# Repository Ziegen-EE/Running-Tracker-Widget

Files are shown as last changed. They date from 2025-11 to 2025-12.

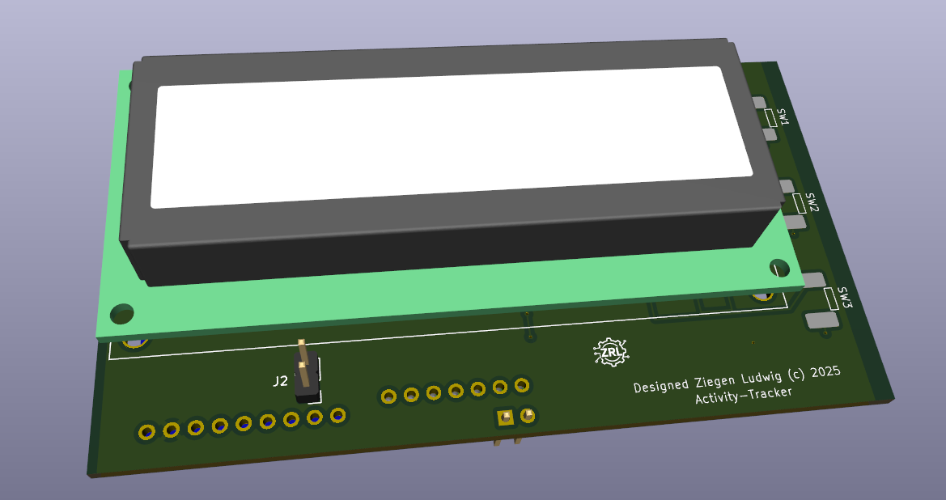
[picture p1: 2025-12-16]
Running-Tracker/KiCad/PCB/3D_PCB.png

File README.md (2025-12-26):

# Running Tracker Widget  
*A compact Arduino-based wearable for tracking pace, distance, and run duration.*

---

## Overview
The **Running Tracker Widget** is a portable, battery-powered device designed to measure and display **running metrics** such as **pace**, **distance**, and **elapsed time**.  
Built around the **Arduino Pro Mini**, this system integrates GPS positioning, user controls, and a display interface to deliver accurate real-time tracking data in a lightweight form factor.  

This project highlights hands-on skills in **embedded systems**, **circuit design**, and **hardware integration**, forming a complete end-to-end electrical engineering prototype.

---

## System Features
- **Arduino Pro Mini Core** – Compact 5V microcontroller board for low-power applications  
- **Adafruit Ultimate GPS Module** – Provides accurate positional data (lat/lon, altitude, speed, and time)  
- **LCD Display with Adjustable Resistor** – Displays pace, distance, and time in real-time  
- **Pololu LV Power Switch** – Enables safe and efficient power management for battery use  
- **User Input Buttons** – Right-angle momentary push buttons for start/stop and mode navigation  
- **Passive Components** – Decoupling capacitors and precision resistors for signal stability and protection  
- **9V Battery Snap Connector** – Supports portable power input with quick connection  

---

## Bill of Materials (BOM)

You can view the full interactive BOM spreadsheet here:  
👉 [**Running Tracker BOM – Google Sheets**](https://docs.google.com/spreadsheets/d/1CWu7IO52Xdz1FhUTgCzN4FMrNsjh3O-xI5pumeO5So4/edit?usp=sharing)

| # | Component | Manufacturer | MPN | Qty | Description / Notes |
|---|---|---|---|-----|---|
| 1 | Arduino Pro Mini Socket | SparkFun | DEV-11113 | 1 | 5V, 16MHz, core microcontroller board |
| 2 | Adafruit Ultimate GPS | Adafruit | 746 | 1 | High-accuracy GPS module with integrated antenna |
| 3 | Pololu LV Power Switch | Pololu | 2808 | 1 | Low-voltage switch for efficient battery control |
| 4 | LCD + Variable Resistor | Adafruit | 181 | 1 | Display and control interface |
| 5 | Right Angle Push Button | C&K | 611-KSS223GLFG | 3 | User input buttons |
| 6 | Capacitor 10µF | TAIYO YUDEN | MCASL21GBB7106KTNA01 | 1 | Power line stabilization |
| 7 | Capacitor 0.1µF | KYOCERA AVX | KAM21BR71H104JM | 1 | Signal filtering |
| 8 | Resistor 220Ω | Panasonic | ERJ-S06F2200V | 1 | Current limiting |
| 9 | Resistor 10kΩ | KOA Speer | SG73P2ARTTD103G | 3 | Voltage division and logic pull-ups |
| 10 | 9V Battery Snap | Bourns | LS-00033 | 1 | Power supply connector |

---

## Functional Overview
1. **GPS Data Acquisition:** The Adafruit GPS module provides NMEA data for time, position, and velocity.  
2. **Microcontroller Processing:** The Arduino Pro Mini calculates pace and distance based on GPS data.  
3. **User Interaction:** Push buttons allow start/stop control and data viewing.  
4. **Display Output:** The LCD module shows real-time run statistics.  
5. **Power Regulation:** The Pololu switch ensures stable and safe power control from a 9V source.

---

## Technical Specifications
- **Operating Voltage:** 5V  
- **Input Power:** 9V battery (via snap connector)  
- **Microcontroller:** ATmega328P (Arduino Pro Mini)  
- **Display Interface:** Parallel/Serial LCD  
- **Sensors:** GPS (Adafruit Ultimate GPS)  
- **User Inputs:** 3x push buttons  
- **Enclosure:** Compatible with 3D-printed housing or handheld casing  

---

## Development Tools
- **IDE:** Arduino IDE  
- **Language:** C/C++  
- **Libraries:** `Adafruit_GPS`, `LiquidCrystal`, `SoftwareSerial`  
- **Simulation / Schematic:** KiCad or EasyEDA  

---

## Future Enhancements
- Add accelerometer or IMU sensor for step-based distance correction  
- Integrate Bluetooth for mobile sync  
- Log data to microSD for long-term performance tracking  
- Optimize firmware for lower power consumption

---

### PCB Manufacturing
The PCB layout and Gerber files were created following **[3DayPCBs](https://3daypcbs.com)** standard manufacturing specifications.  
Key parameters include:
- 1.6 mm board thickness  
- 1 oz copper weight  
- 6 mil minimum trace/space  
- Standard FR-4 substrate  
- Through-hole and SMD mixed design  

Compatibility with other PCB manufacturers may require DRC rule adjustments.

---

## License
This project is licensed under the [MIT License](LICENSE).  
Feel free to use and modify with attribution.

**PCB Design Notice:**  
All PCB and Gerber files included in this repository are designed according to **[3DayPCBs](https://3daypcbs.com)** manufacturing specifications, including board thickness, copper weight, trace width, and drill tolerances.  
Users adapting the design for other manufacturers should verify compatibility and adjust design rules accordingly.

---

## Acknowledgments

This project makes use of the [Arduino KiCad Library](https://github.com/Alarm-Siren/arduino-kicad-library)  
by **Alarm-Siren**, distributed under the [MIT License](https://github.com/Alarm-Siren/arduino-kicad-library/blob/main/LICENSE).

The library was used for schematic and footprint references during PCB design.

---

## Sponsorship & Support

This project is proudly supported by the  
**[School District 38 CTE (Career & Technical Education) Program](https://www.lewispalmer.org/cte)**.  

Their sponsorship provided access to electronic components, fabrication tools, and resources essential for the development and testing of the Activity Tracker Widget.  
Special thanks to the instructors and staff who promote hands-on STEM and engineering education.

## PCB Manufacturing Support

PCB fabrication for this project can be reliably handled by **PCBWay**, a professional PCB manufacturing and assembly service widely used for prototyping and medium to large-scale production.

PCBWay is well-suited for projects like my **Running Tracker Widget**, which combine through-hole and SMD components in a compact embedded design. Their capabilities support iterative hardware development and manufacturing constraints common in wearable and portable electronics.

### Relevant Capabilities
- Standard **FR-4 PCB fabrication** with configurable thickness and copper weight  
- Support for **mixed through-hole and SMD designs**  
- Optional **PCB assembly (PCBA)** for populated boards  
- Fast turnaround times suitable for prototyping and validation  

Design files created for this project are adapted for 3DayPCBs, although manufacturing specifications are well within their capabilities!!!

Additional information is available at:  
👉 **https://www.pcbway.com**

PCBWay actively supports open-source hardware projects and educational engineering development.

---

## Author
**[Ziegen Ludwig]**  
Electrical Engineering Student | Embedded Systems Developer  
🔧 *Focused on IoT, microcontroller design, and wearable electronics.*

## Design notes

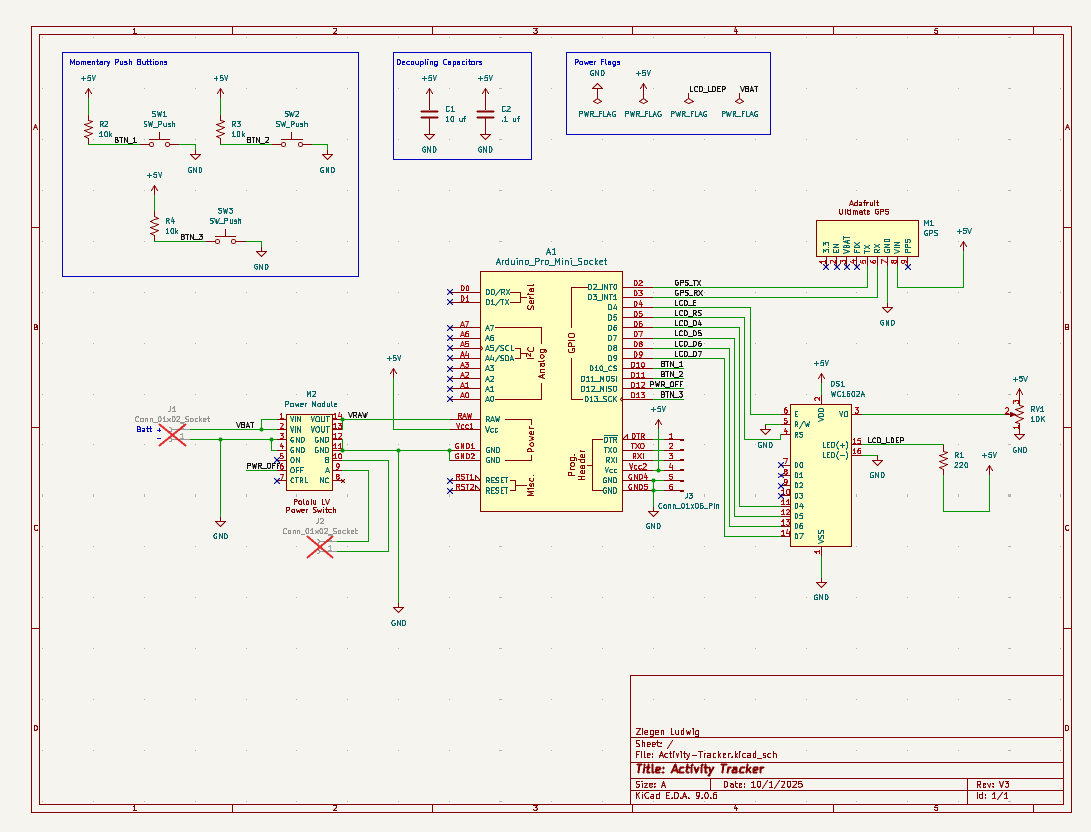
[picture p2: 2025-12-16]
Running-Tracker/KiCad/Schematic/schematic.png.png

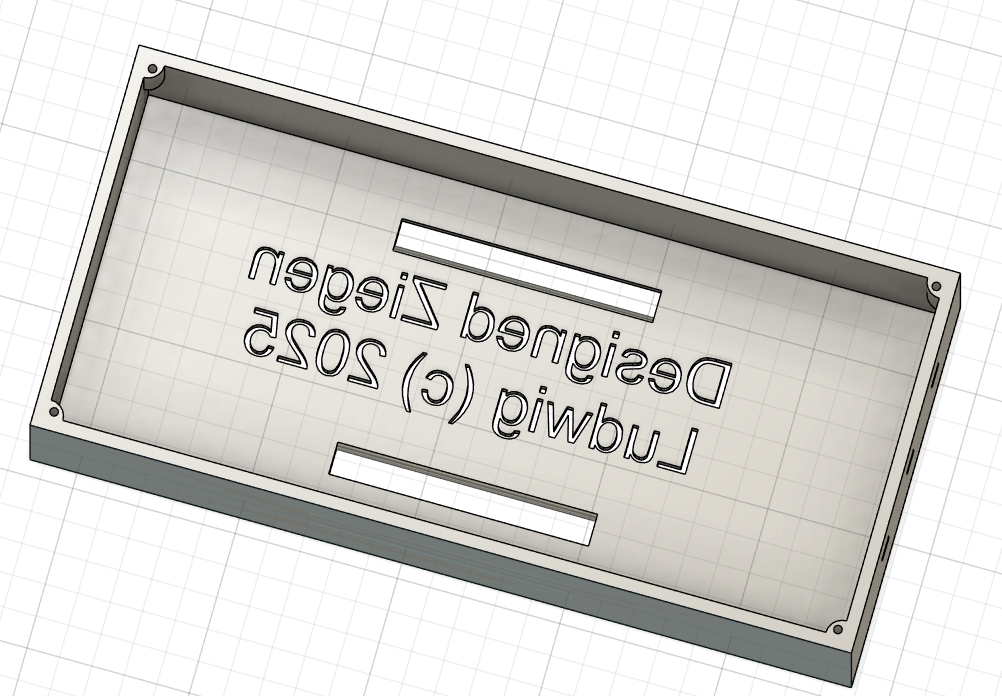
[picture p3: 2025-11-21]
Running-Tracker/3D-Modeled-Case/Running-Tracker-Base.png

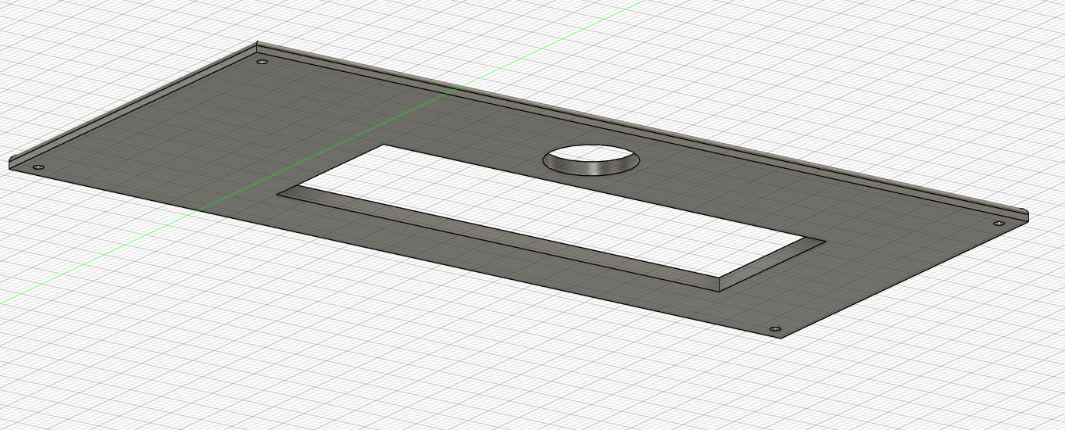
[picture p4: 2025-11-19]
Running-Tracker/3D-Modeled-Case/Running-Tracker-Lid.png

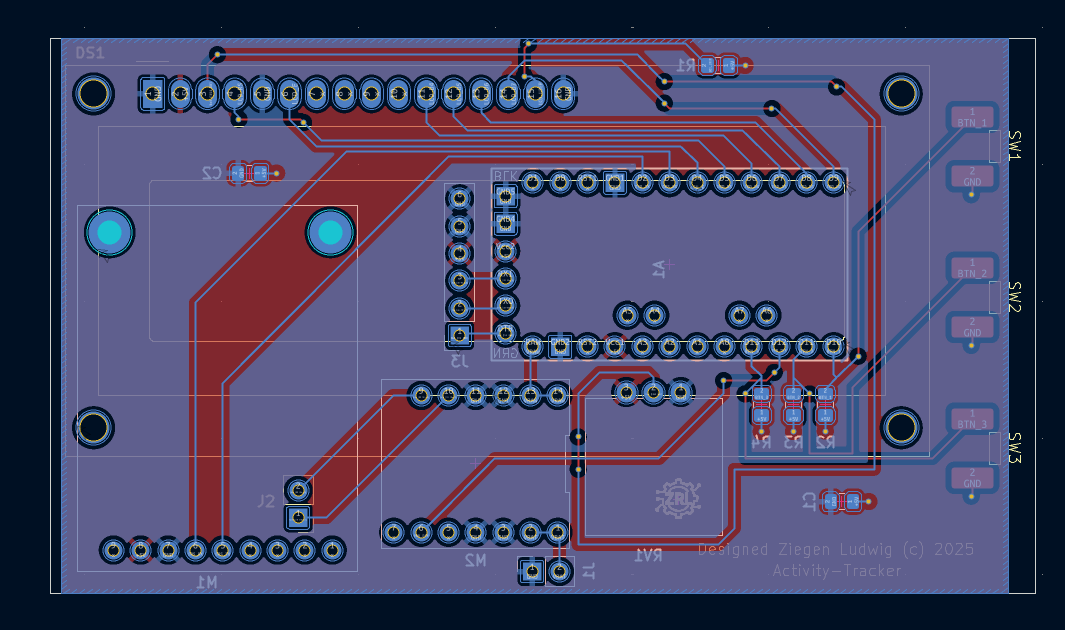
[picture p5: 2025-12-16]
Running-Tracker/KiCad/PCB/2D_PCB.png

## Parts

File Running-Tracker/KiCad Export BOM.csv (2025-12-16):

Reference | Qty | Value | DNP | Exclude from BOM | Exclude from Board | Footprint | Datasheet
A1 | 1 | Arduino_Pro_Mini_Socket |  |  |  | arduino-library:Arduino_Pro_Mini_Socket | https://docs.arduino.cc/retired/boards/arduino-pro-mini
C1 | 1 | 10 uf |  |  |  | Capacitor_SMD:C_0805_2012Metric_Pad1.18x1.45mm_HandSolder | ~
C2 | 1 | .1 uf |  |  |  | Capacitor_SMD:C_0805_2012Metric_Pad1.18x1.45mm_HandSolder | ~
DS1 | 1 | WC1602A |  |  |  | Display:WC1602A | http://www.wincomlcd.com/pdf/WC1602A-SFYLYHTC06.pdf
J1,J2 | 2 | Conn_01x02_Socket | DNP |  |  | Connector_PinHeader_2.54mm:PinHeader_1x02_P2.54mm_Vertical | ~
J3 | 1 | Conn_01x06_Pin |  |  |  | Connector_PinHeader_2.54mm:PinHeader_1x06_P2.54mm_Vertical | ~
M1 | 1 | GPS |  |  |  | Adafruit:Adafruit Ultimate GPS
M2 | 1 | Power Module |  |  |  | Pololu_PWR_SW_LV:Pololu LV Power Switch
R1 | 1 | 220 |  |  |  | Resistor_SMD:R_0805_2012Metric_Pad1.20x1.40mm_HandSolder | ~
R2,R3,R4 | 3 | 10k |  |  |  | Resistor_SMD:R_0805_2012Metric_Pad1.20x1.40mm_HandSolder | ~
RV1 | 1 | 10K |  |  |  | Potentiometer_THT:Potentiometer_Vishay_148-149_Single_Vertical | ~
SW1,SW2,SW3 | 3 | SW_Push |  |  |  | KSS223G_LFG:KSS223G LFG | ~

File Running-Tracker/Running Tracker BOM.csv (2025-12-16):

Column 1 | Reference Designator | DNP | Part Name | Manufacturer | MPN | Qty | Footprint | Link | Notes | Price | Total Price
1 | A1 | No | Arduino Pro Mini Socket | SparkFun | DEV-11113 | 1 | Module | Link | 5v | 11.25 | 100.07
2 | M1 | No | Adafruit Ultimate GPS | Adafruit | 746 | 1 | Module | Link |  | 29.95
3 | M2 | No | Pololu LV Power Switch | Pololu | 2808 | 1 | Module | Link |  | 4.95
4 | DS1 | No | LCD + Varible Resistor | Adafruit | 181 | 1 | Module | Link |  | 9.95
5 | SW1, SW2, SW3 | No | Right Angle Momentary Push Button | C&K | 611-KSS223GLFG | 3 | SMD | Link |  | 0.97
6 | C1 | No | Capacitor | TAIYO YUDEN | MCASL21GBB7106KTNA01 | 1 | SMD | Link | 10uF | 0.45
7 | C2 | No | Capacitor | KYOCERA AVX | KAM21BR71H104JM | 1 | SMD | Link | .1uF | 0.2
8 | R1 | No | Resistor | Panasonic | ERJ-S06F2200V | 1 | SMD | Link | 220 | 0.31
9 | R2, R3, R4 | No | Resistor | KOA Speer | SG73P2ARTTD103G | 3 | SMD | Link | 10K | 0.22
10 | J1 | Yes | 9V Battery Snap-On | Bourns | 375-LS-00033 | 1 | N/a | Link |  | 3.14
11 | J2 | Yes | Momentary Push Button | Adafruit | 1505 | 1 | N/a | Link |  | 0.95
12 | J3 | No | 1x6 Vertical Pin Header | Amphenol FCI | 649-68001-406HLF | 1 | Pin Strip | Link |  | 0.34
13 | N/a | Yes | 3D Modeled Case | N/a | N/a | 1 | N/a | N/a |  | 0
14 | N/a | Yes | Battery | Amazon (Hovxjzk) | N/a | 1 | N/a | Link | 9V, 1200mAh | 12.9
15 | N/a | Yes | Coin Battery | Murata Electronics | 490-18640-ND | 2 | N/a | Link | CR1220 | 0.86
16 | N/a | Yes | UART Connector | Adafruit | 284 | 1 | N/a | Link |  | 14.75
17 | N/a | Yes | External Antenna | Adafruit | 2461 | 1 | N/a | Link |  | 3.95
18 | N/a | Yes | 1x16 Vertical Pin Header | Elecbee | N/a | 1 | Pin Strip | Link |  | 1.69
19 | N/a | N/a | PCB Board | N/a | N/a | 5 | N/a | Link |  | 0

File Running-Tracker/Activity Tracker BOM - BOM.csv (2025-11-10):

Item # | Reference Designator | DNP | Part Name | Manufacturer | MPN | Qty | Footprint | Link | Notes | Price | Total Price
1 | A1 | No | Arduino Pro Mini Socket | SparkFun | DEV-11113 | 1 | Module | Link | 5v | 11.25 | 143.46
2 | M1 | No | Adafruit Ultimate GPS | Adafruit | 746 | 1 | Module | Link |  | 29.95
3 | M2 | No | Pololu LV Power Switch | Pololu | 2808 | 1 | Module | Link |  | 4.95
4 | DS1 | No | LCD + Varible Resistor | Adafruit | 181 | 1 | Module | Link |  | 9.95
5 | SW1, SW2, SW3 | No | Right Angle Momentary Push Button | C&K | 611-KSS223GLFG | 3 | SMD | Link |  | 0.97
6 | C1 | No | Capacitor | Samsung Electro-Mechanics | CL05A106MP5NUNC | 1 | SMD | Link | 10uF | 0.08
7 | C2 | No | Capacitor | Murata Electronics | GRM033C71C104KE14D | 1 | SMD | Link | .1uF | 0.08
8 | R1 | No | Resistor | Bourns | 652-CR01005AFW4702GA | 1 | SMD | Link | 220 | 0.18
9 | R2, R3, R4 | No | Resistor | Bourns | 652-PWR6927W1002FE | 3 | SMD | Link | 10K | 4.09
10 | J1 | Yes | 9V Battery Snap-On | Bourns | 375-LS-00033 | 1 | N/a | Link |  | 3.14
11 | J2 | Yes | Momentary Push Button | Adafruit | 1505 | 1 | N/a | Link |  | 0.95
12 | J3 | No | 1x6 Vertical Pin Header | Amphenol FCI | 649-68001-406HLF | 1 | Pin Strip | Link |  | 0.34
13 | N/a | Yes | 3D Modeled Case | N/a | N/a | 1 | N/a | N/a |  | 0
14 | N/a | Yes | Battery | Amazon (Hovxjzk) | N/a | 1 | N/a | Link | 9V, 1200mAh | 12.9
15 | N/a | Yes | Coin Battery | Murata Electronics | 490-18640-ND | 2 | N/a | Link | CR1220 | 0.86
16 | N/a | Yes | UART Connector | Adafruit | 284 | 1 | N/a | Link |  | 14.75
17 | N/a | Yes | External Antenna | Adafruit | 2461 | 1 | N/a | Link |  | 3.95
18 | N/a | Yes | 9V Snap-On Lead | OSEPP Electronics | LS-00033 | 1 | N/a | Link |  | 3.14
19 | N/a | Yes | 1x16 Vertical Pin Header | Elecbee | N/a | 1 | Pin Strip | Link |  | 1.69
20 | N/a | N/a | PCB Board | PCBWay | N/a | 1 | N/a | Link | QTY. 5 | 29.26

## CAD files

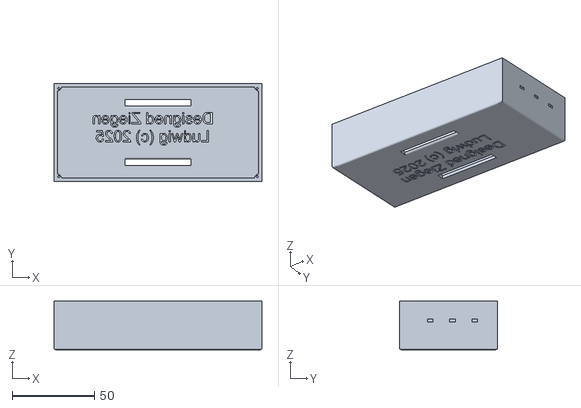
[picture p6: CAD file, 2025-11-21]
Running-Tracker/3D-Modeled-Case/Running-Tracker_Base.stl
126.5 x 59.5 x 29.5

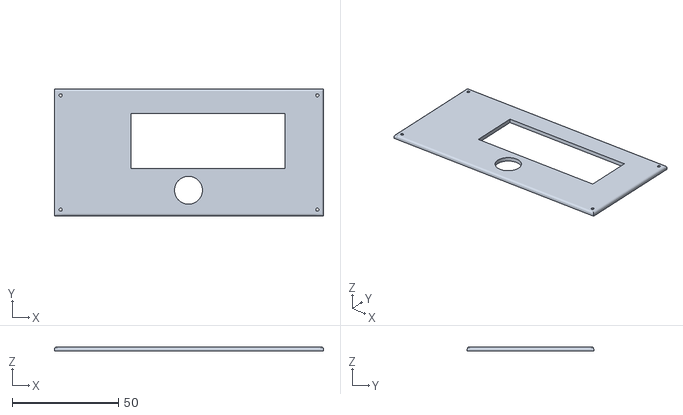
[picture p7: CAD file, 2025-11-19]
Running-Tracker/3D-Modeled-Case/Running-Tracker_Lid.stl
126.5 x 59.5 x 2.00

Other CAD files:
Running-Tracker/3D-Modeled-Case/F360 Case Components/Running-Tracker_Base.f3d
Running-Tracker/3D-Modeled-Case/F360 Case Components/Running-Tracker_Lid.f3d

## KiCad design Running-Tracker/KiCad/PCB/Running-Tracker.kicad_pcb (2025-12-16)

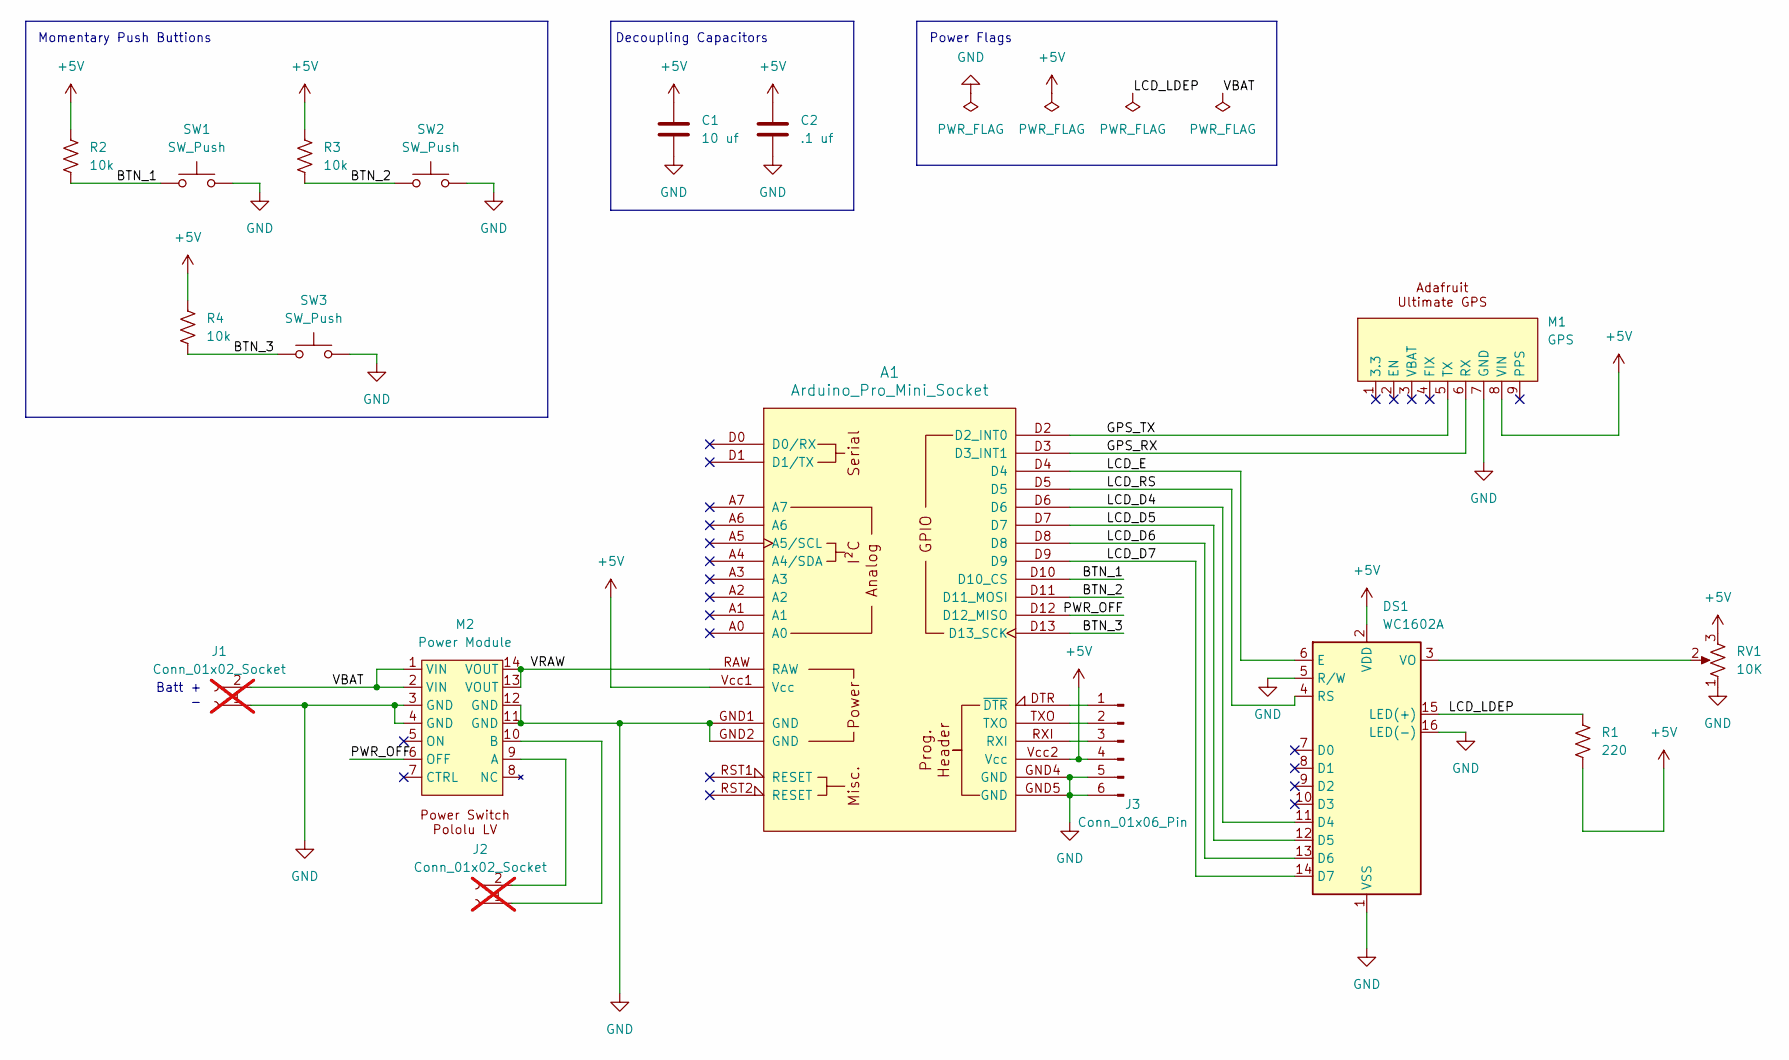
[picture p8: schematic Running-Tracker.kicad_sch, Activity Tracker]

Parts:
A1: Arduino_Pro_Mini_Socket; MPN DEV-11113
C1: 10 uf; C_0805_2012Metric_Pad1.18x1.45mm_HandSolder; MPN CL05A106MP5NUNC
C2: .1 uf; C_0805_2012Metric_Pad1.18x1.45mm_HandSolder; MPN GRM033C71C104KE14D
DS1: WC1602A; MPN 181
J1: Conn_01x02_Socket; PinHeader_1x02_P2.54mm_Vertical; MPN 375-LS-00033; not fitted
J2: Conn_01x02_Socket; PinHeader_1x02_P2.54mm_Vertical; MPN 1505; not fitted
J3: Conn_01x06_Pin; PinHeader_1x06_P2.54mm_Vertical; MPN 649-68001-406HLF
M1: GPS; Adafruit Ultimate GPS; MPN 746
M2: Power Module; Pololu LV Power Switch; MPN 2808
R1: 220; R_0805_2012Metric_Pad1.20x1.40mm_HandSolder; MPN 652-CR01005AFW4702GA
R2, R3, R4: 10k; R_0805_2012Metric_Pad1.20x1.40mm_HandSolder; MPN 652-PWR6927W1002FE
RV1: 10K; Potentiometer_Vishay_148-149_Single_Vertical; MPN 181
SW1, SW2, SW3: SW_Push; KSS223G LFG; MPN 611-KSS223GLFG

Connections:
+5V: A1.Vcc1 (Vcc), A1.Vcc2 (Vcc), C1.1, C2.1, DS1.2 (VDD), J3.4, M1.8 (VIN), R1.1, R2.1, R3.1, R4.1, RV1.3
/BTN_1: A1.D10 (D10_CS), R2.2, SW1.1
/BTN_2: A1.D11 (D11_MOSI), R3.2, SW2.1
/BTN_3: A1.D13 (D13_SCK), R4.2, SW3.1
/GPS_RX: A1.D3 (D3_INT1), M1.6 (RX)
/GPS_TX: A1.D2 (D2_INT0), M1.5 (TX)
/LCD_D4: A1.D6, DS1.11 (D4)
/LCD_D5: A1.D7, DS1.12 (D5)
/LCD_D6: A1.D8, DS1.13 (D6)
/LCD_D7: A1.D9, DS1.14 (D7)
/LCD_E: A1.D4, DS1.6 (E)
/LCD_LDEP: DS1.15 (LED(+)), R1.2
/LCD_RS: A1.D5, DS1.4 (RS)
/PWR_OFF: A1.D12 (D12_MISO), M2.6 (OFF)
/VBAT: J1.2, M2.1 (VIN), M2.2 (VIN)
/VRAW: A1.RAW, M2.13 (VOUT), M2.14 (VOUT)
GND: A1.GND1 (GND), A1.GND2 (GND), A1.GND4 (GND), A1.GND5 (GND), C1.2, C2.2, DS1.1 (VSS), DS1.5 (R/W), DS1.16 (LED(-)), J1.1, J3.5, J3.6, M1.7 (GND), M2.3 (GND), M2.4 (GND), M2.11 (GND), M2.12 (GND), RV1.1, SW1.2, SW2.2, SW3.2
unnamed: A1.DTR (~DTR), J3.1
unnamed: DS1.3 (VO), RV1.2
unnamed: J2.1, M2.10 (B)
unnamed: J2.2, M2.9 (A)
unnamed: A1.TXO, J3.2
unnamed: A1.RXI, J3.3

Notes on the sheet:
Decoupling Capacitors
Power Flags
Batt + -
Momentary Push Buttions

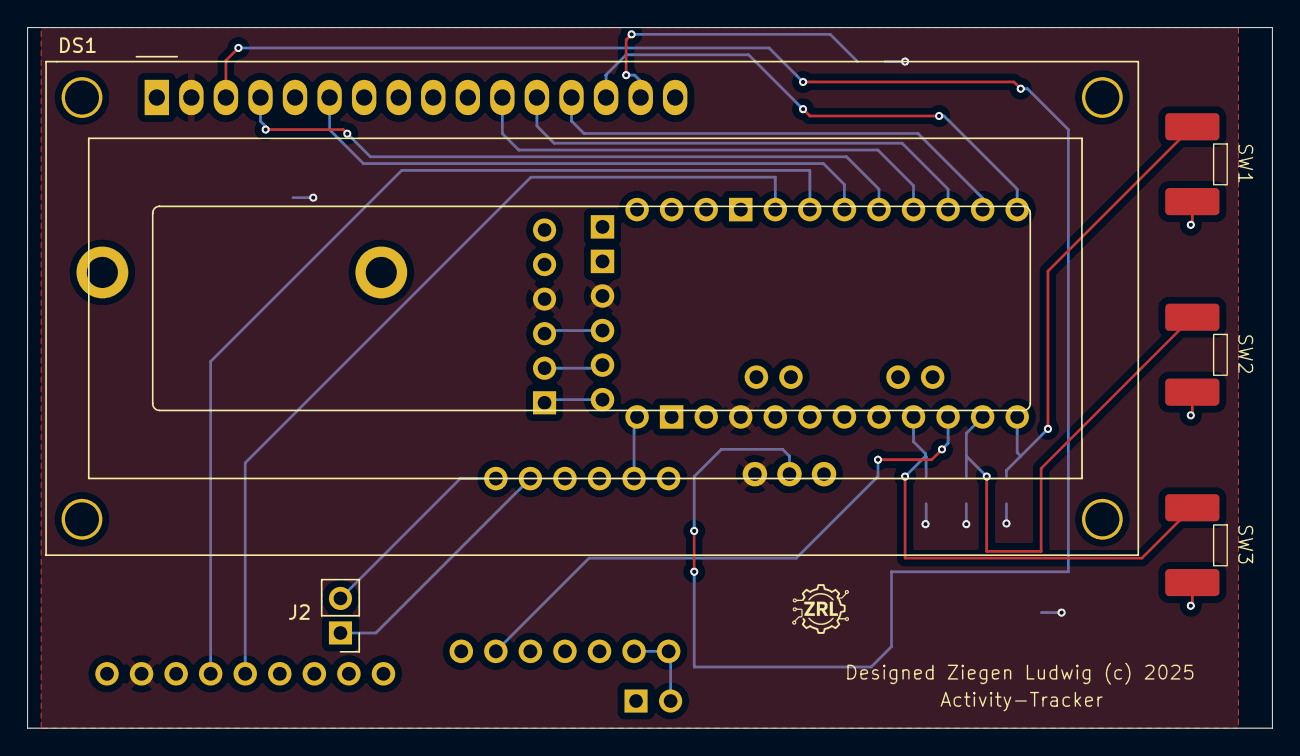
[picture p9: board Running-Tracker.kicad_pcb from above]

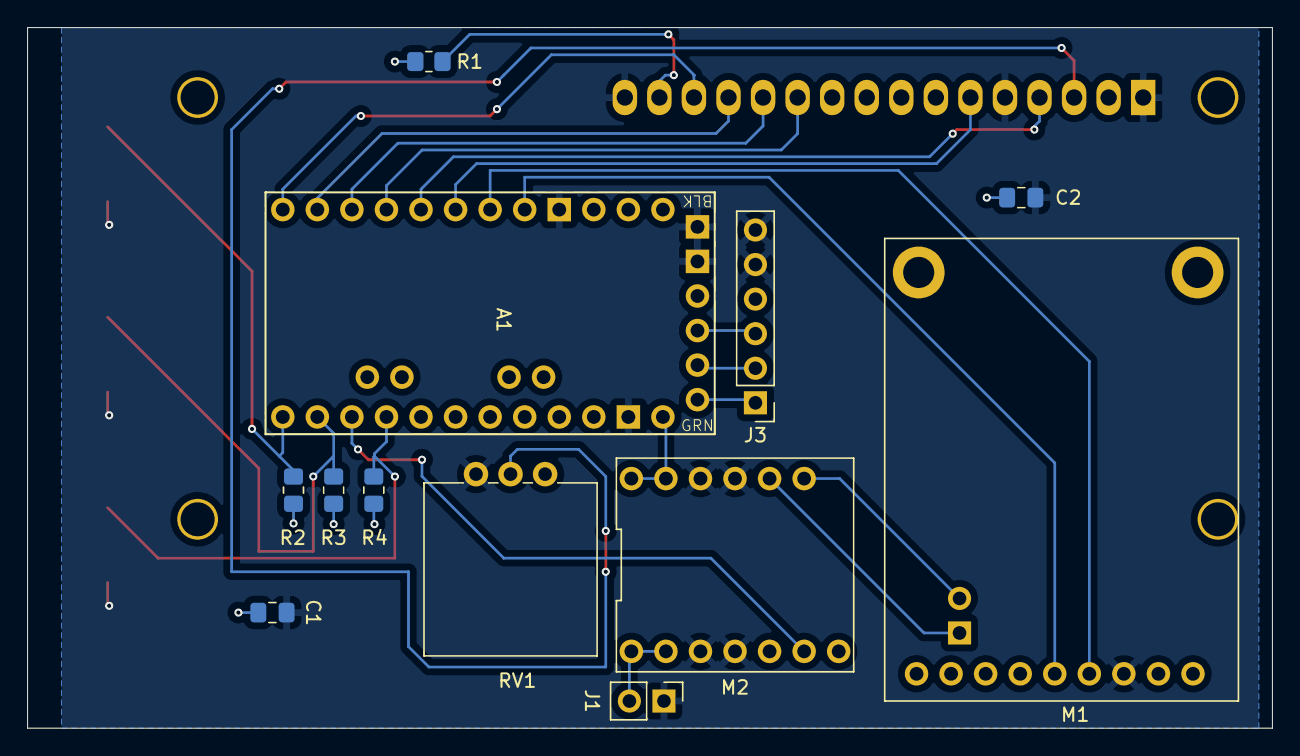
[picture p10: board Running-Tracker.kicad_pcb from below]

Board: 2 copper layers, 91.5 x 51.5 mm, 17 parts (12 on the bottom side), 23 nets.

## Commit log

2025-11-10 Add direct csv file
    [Activity Tracker BOM - BOM.csv]
2025-11-10 Update and rename Activity Tracker BOM - BOM.csv to Activity Tracker BOM.csv
    [Activity Tracker BOM.csv]
2025-11-10 add Schematic PNG
2025-11-10 Update and rename Activity Tracker BOM.csv to Running Tracker BOM.csv
    [Running Tracker BOM.csv]
2025-11-10 Update and rename Activity-Tracker.kicad_sch to Running-Tracker.kicad_sch
    [Running-Tracker.kicad_sch]
2025-11-10 Update and rename Activity-Tracker.kicad_pcb to Running-Tracker.kicad_pcb
    [Running-Tracker.kicad_pcb]
2025-11-12 Update and rename Running-Tracker/KiCad/Schematic/Activity-Tracker.kicad_sch to Running-Tracker/KiCad/Running-Tracker.kicad_sch
    [Running-Tracker.kicad_sch]
2025-12-26 Add PCBWay support section to README
    Expanded the README to include detailed information about PCBWay's capabilities and support for the project, emphasizing its suitability for the Running Tracker Widget. Forgot to push.

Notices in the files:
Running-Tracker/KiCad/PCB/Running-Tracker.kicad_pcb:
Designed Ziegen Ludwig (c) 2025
